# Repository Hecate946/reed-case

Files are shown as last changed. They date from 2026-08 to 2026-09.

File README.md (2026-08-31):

# Reed case CAD

OpenSCAD source for the current H946 reed-case prototype.

## Closure hardware

The custom pushbutton / leaf-spring / hook / striker system has been removed.
The case now mounts one purchased **Alise CA100S-4P (CA100-4P) 40 mm double-roller catch** centered in the front service strip. The roller body sits on an integrated base pedestal just below the case seam; the matching striker screws to a recessed ledge on the lid. There is no external button. Pulling the lid apart releases the rollers.

Useful OpenSCAD views:

```scad
view = "roller_catch_mechanism";
view = "roller_catch_hardware";
view = "case_open";
view = "case_closed";
```

The purchased catch is not exported as a printable part. `make export-case` exports the base and lid with the mounting bosses, locating seats, and screw pilots already integrated.

### Flush Alise catch integration
The centered front catch housing now uses the seller drawing directly: the 40 x 9 mm, 10 mm-high main catch sits in a top-loading recess molded into a locally 12.8 mm-thick front wall. The exterior remains seamless. The 22 x 8 mm striker plate is recessed flush into the lid rim, with only its 5 mm tongue projecting into the rollers. The ordinary shell remains 4.2 mm thick away from the catch.

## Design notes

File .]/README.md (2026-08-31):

# Reed case CAD

OpenSCAD source for the **premium-style clarinet reed case prototype**.
The project is intentionally small: one tray design, one enclosure design, one
configuration file, and one source-zip script.

## Prototype concept

- compact **190 x 99 x 31.5 mm** enclosure sized around one full-width 10x2 reed cartridge
- integrated shallow **humidity bay** below the cartridge, holding **2 x Boveda Size 8** packs under a simple vented drop-in cover
- one removable double-sided 10-reed-per-face tray / cartridge
- four D4x2 retention points per tray
- replaceable **2 mm metal hinge pin** with alternating printed knuckles
- two full-height, sharp-cornered mirrored stepped spring-support blocks
- separate moving latch plate with a large **48 x 6.65 mm** exterior push button
- one closing tongue with a `---\` outward face and a flat-underside catch
- no guide rails and no stop tabs; the inner front wall is the locked stop
- shallow slide pan recessed into the base floor, outer bottom shell intact
- no modeled spring; the future leaf spring remains a separate metal part
- recessed lid latch groove with no protruding lid striker
- continuous **2 x 175 mm silicone O-ring** prototype seal
- shallow `ASASI` mark at the lid's bottom right, controlled from `src/config.scad`
- dark-teal shell / white-tray colors in OpenSCAD previews only

The cartridge sits on a raised support frame above the humidity bay, leaving a
vented service cavity below for the two Boveda packs. The side-latch hardware stays
in its own narrow service strips beside the cartridge.

### Leaf-spring mounting architecture

Only the case-side stepped solids exist in CAD. They intentionally have no
screw holes, spring channels, rounded corners, or enclosed cutouts. From the
top, each has a full-width back section and a half-width outward front leg;
the right piece is the exact horizontal mirror of the left. Open
`bottom_case` to debug the bottom piece alone; the real fused mount solids are
orange. Use `leaf_spring_mount_pair` to inspect both blocks without the
case. `left_leaf_spring_mount` and `right_leaf_spring_mount` expose each module
separately for dimension changes and standalone STL checks.
Each piece fits within a **13.0 x 8.5 x 8.45 mm** envelope and extends from the
base floor to the case seam. The front step depth and outer-foot width are
separate parameters in `src/config.scad`. The mount centers sit at **-42 and
+42 mm**, so the real leaf spring spans about 84 mm between the outer feet.
That span is deliberate: it clears the much wider latch plate. Expect to need
**0.5 mm or thicker** spring steel, because a thin 0.3 mm leaf over this span
delivers well under 1 N at full travel and feels dead.

### Moving latch piece

The latch is a separate component rather than part of the printable base. It is
a single flat plate, **56.0 x 4.0 mm** in plan, sliding in a **1.00 mm** deep pan
recessed into the interior base floor. The pan leaves **2.80 mm** of floor skin
and never breaks the exterior bottom shell. The pan's side walls guide the plate
in X; its rear wall sits 0.30 mm behind the fully pressed position and acts only
as an overtravel backstop.

There are no guide rails and no stop tabs anywhere in the design. At rest the
leaf spring pushes the plate outward until its full-width front face lands flat
on the inner front wall, so the locked stop is 56 mm of wall instead of two
small tabs.

Dropping the plate into the pan is what lets the button grow. The interior floor
sits above the exterior mid-plane, so a vertically centered button on the base
face is height-limited by the floor; the pan removes that limit. The integral
button is now **48.0 x 6.65 mm** with a **2.60 mm** corner radius, covering about
**13.7%** of the front face. Its center is derived from `x = 0` and
`z = v2_base_h / 2`, so it stays exactly centered. Its **2.60 mm** travel leaves
it exactly flush with the case wall when fully pressed.

#### Closing tongue and catch

One solid rises above the seam. Read its outward face top-down and it is
literally `---\`: a flat crown, then a single straight ramp falling outward to a
protruding catch. The descending lid wall rides that ramp and drives the whole
latch inward; when the lid pocket lines up, the spring snaps the catch in. Every
convex edge carries one **0.55 mm** radius and the single concave corner carries
a **0.35 mm** fillet.

The catch underside is **horizontal**. This is the important change from the old
hook. The seal load presses straight up into a flat **1.0 mm** deep bearing land
and cannot back-drive the latch. Previously the only thing holding the lid was a
sloped hook top at roughly 35 degrees, which meant the O-ring's own force was
continuously trying to eject the latch and the leaf spring was fighting the seal
the entire time the case was closed. Nothing carries the lock now except that
flat land.

Sequence: press the lid down to the seam, the catch slips in with **0.20 mm** of
room above and below, release, and the seal lifts the lid **0.20 mm** until the
pocket floor lands on the land. Locked O-ring squeeze is **0.35 mm**, about
17.5% of the 2 mm cord. Pressing the button retracts the catch **1.55 mm** past
the wall face, with 1.05 mm of travel to spare.

The tongue is set back **0.50 mm** from the plate's front face. Without that
setback the fillet under the catch, not the flat land, would be the first thing
the lid pocket touches, and the seat height would be wrong. `make check` catches
that case directly.

#### Lid pocket

The lid owns only a plain rounded pocket, **22.6 mm** wide and **1.80 mm** deep,
leaving **1.60 mm** of solid outer wall skin. Its floor sits **2.80 mm** above the
seam. The previous version placed it 1.60 mm above the seam, which left only
**0.15 mm** of lid material between the O-ring gland roof and the pocket floor.
That web is unprintable; it is now **1.35 mm** and is asserted.

The pocket roof is derived, not hand-set: it clears the point where the closing
ramp crosses the lid wall face, plus 0.25 mm. Change the tongue height or the
catch extension and the pocket follows.

All functional values are grouped under `MOVING FRONT LATCH PIECE` and
`CLOSING TONGUE AND CATCH` in `src/config.scad`.

#### Known limitation

The button opening is a straight 48 x 6.65 mm hole through the front wall into
the sealed interior. The O-ring seals the lid seam properly and then the case
breathes through the latch. This redesign does not fix that and it is probably
not fixable with an external push button; it needs either a gasketed button boot
or a latch that acts through the seam instead of through the wall. Decide that
before treating the Boveda humidity behaviour as real.

#### Views

Use `bottom_case` for the installed assembly, `bottom_case_shell` for the base
and its openings alone, `bottom_case_latch_fit` for a transparent fit view, and
`bottom_case_latch_pressed` for maximum inward travel.
`latch_groove_lock_detail` shows the catch seated on its land at the resting lid
height, `latch_groove_closing_entry` shows the moment of entry with the lid
pressed to the seam, `latch_button_release_detail` shows the catch fully
retracted, and `top_lid_latch_groove` isolates the pocketed center-front lid
section. Use `latch_piece` for the standalone moving component.

Use `humidity_cassette` or `humidity_bay_open` to inspect the humidity bay with its cover lifted.
Use `humidity_bay_closed` to preview the lid seated on its ledge.
`case_exploded` now shows the base, the vented humidity cover over two packs, the full reed
cartridge above it, and the lid.

## Files that matter

```text
src/config.scad          dimensions + hardware + easy customization
src/main.scad            interactive OpenSCAD preview
src/assembly.scad        views and part routing
src/parts/tray.scad      reed tray geometry
src/parts/case.scad      enclosure geometry
src/parts/spring_mounts.scad
src/parts/calibration.scad
src/lib/                 small reusable geometry/hardware helpers
Makefile                 all checks / exports
scripts/make-source-zip.sh
```

## Normal workflow

Open `src/main.scad` in OpenSCAD. The file intentionally keeps every useful
`view = ...` option commented directly below the active fine-mesh view, so
switching views stays one-line simple:

```text
bottom_case
humidity_cassette
bottom_case_boveda_size_60
bottom_case_shell
bottom_case_latch_fit
bottom_case_latch_pressed
latch_piece
latch_groove_lock_detail
latch_groove_closing_entry
latch_button_release_detail
top_lid_latch_groove
leaf_spring_mount_pair
left_leaf_spring_mount
right_leaf_spring_mount
case_open
case_closed
case_exploded
case_closed_front
bottom_case_with_trays
lid_seal
tray
print_layout
```

All functional dimensions are in `src/config.scad`.

### Reed reference model

Preview reeds use the footprint and thickness envelope of a French/Boehm Bb
clarinet reed: **67.5 mm long, 13.15 mm maximum width, 11.0 mm heel width,
34.1 mm vamp, 3.05 mm nominal heel thickness, and 0.10 mm tip thickness**.
The intended reference is the Vandoren Traditional Bb strength 3.5 (CR1035).
Vandoren identifies that product/strength but does not publish its proprietary
full manufacturing profile, so the preview uses documented clarinet-reed
measurements for fit and clearance rather than claiming an exact factory cut.

### Easy tray exports

From the project root, use whichever one you need:

```bash
make export-tray-full         # complete assembled tray -> one STL
make export-humidity-cover    # vented humidity cover
make export-tray-face-a       # only face A
make export-tray-face-b       # only face B
make export-tray              # both support-free shell halves
```

By default these use the fast prototype mesh. For the final/high-quality mesh, add `PROFILE=fine`:

```bash
make export-tray-full PROFILE=fine
```

The single-part outputs are written to:

```text
build/reed-case-prototype/tray/tray_complete.stl
build/reed-case-prototype/tray/tray_face_a.stl
build/reed-case-prototype/tray/tray_face_b.stl
```

Run `make help` at any time to see every available command.

### Export the prototype

```bash
make check
make export
```

The printable files are written to:

```text
build/reed-case-prototype/case_base.stl
build/reed-case-prototype/case_lid.stl
build/reed-case-prototype/latch/latch_piece.stl
build/reed-case-prototype/spring-mounts/left_leaf_spring_mount.stl
build/reed-case-prototype/spring-mounts/right_leaf_spring_mount.stl
build/reed-case-prototype/tray-parts/tray_face_a.stl
build/reed-case-prototype/tray-parts/tray_face_b.stl
build/reed-case-prototype/fit_coupon.stl
```

The current cartridge has **no middle/core layer**. It is built from two
slightly thicker mirrored shell halves that join directly back-to-back.
`make export-tray` exports those two support-free halves; `make export-tray-full`
exports the fused cartridge as one STL. The heel-side 65% uses five smooth
longitudinal breathing runners per reed lane, while the tip-side 35% is fully
open air.

### Quick visual render

```bash
make render
```

This writes the open, closed, front, exploded, tray-fit, and seal views to `build/renders/`.

### Share the latest source

```bash
make zip
```

This always replaces one file at the project root:

```text
reed-case-source.zip
```

Upload that ZIP when you want another design/code pass. There are no dated or
numbered source archives created by the project.

## First physical test

Use inexpensive PLA/PETG. Before committing to a long print, print
`fit_coupon.stl` and verify the actual 2 mm hinge rod and D4x2 hardware fit.
For the complete prototype, install the real hinge pin, magnets/steel targets,
silicone cord used for reed retention, and the intended O-ring. Test the chosen
spring-retention method before installing the real metal spring. Evaluate the case
size, reed access, tray removal, magnet feel, latch force, hinge feel, and seal
compression before changing anything for CNC aluminum.

## Side latch metal hardware

The current case uses two slim side buttons with bowed 301 stainless leaf
springs hidden behind removable stainless cover plates. See
`hardware/SIDE_LATCH_HARDWARE.md`. Export the cutting templates with:

```bash
make export-side-latch-hardware
```

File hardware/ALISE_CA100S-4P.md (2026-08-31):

# Alise CA100S-4P roller catch

Purchased part: Alise 40 mm silver double-roller catch, Amazon ASIN B0D8L6GJWK.
Model: **CA100S-4P**. Manufacturer part: **CA100-4P**.

Seller-published dimensions used by the CAD:

- Main mounting plate: **40 x 9 mm**
- Main mounting-hole pitch: **30 mm**
- Main roller/body span: **24 mm**
- Overall catch height: **10 mm**
- Published mounting-hole diameter: **4 mm**
- Striker mounting plate: **22 x 8 mm**
- Striker mounting-hole pitch: **15 mm**
- Striker tongue rise: **5 mm**

The listing also describes the nominal product envelope as 40 x 25 x 10 mm.
The detailed seller dimension image is used for the mounting plate geometry.
Plate thickness and small radii are not published; the OpenSCAD hardware model
uses preview-only approximations for those non-fit-critical details. Measure the
delivered parts before freezing a production revision.

The printed case has 2.5 mm pilot holes under both pieces. Adjust
`roller_catch_mount_pilot_d` and `roller_catch_strike_pilot_d` in `src/config.scad`
to match the screws you actually use.

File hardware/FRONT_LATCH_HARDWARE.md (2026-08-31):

# Center front-latch hardware

The case uses one centered front push button with the same latch kinematics as
the previous side mechanism: the lid cams the rounded catch inward, the leaf
spring returns the latch outward into the lid groove, and pressing the button
retracts the catch. At full press the button face is flush with the front wall.

## Leaf spring

Prototype material: **301 full-hard stainless spring/shim stock, 0.006 in
(0.1524 mm)**.

Use `front_leaf_spring_strip.dxf` as the cutting/drilling template:

- about 35 mm long x 7 mm high
- two 2.3 mm clearance holes on a 31 mm screw span
- one spring is required

Install it with a shallow outward pre-bow. The exact force should be tuned on a
physical prototype; 0.006 in is the intended starting thickness.

## Interior cover

Use `front_latch_cover_plate.dxf`. Make **one** from:

- 0.030 in / 0.76 mm 304 stainless steel
- deburred edges recommended

The plate screws into the two printed support blocks and hides the spring and
moving latch from the cartridge area. The same two screws clamp the spring ends.

Prototype fasteners:

- 2x M2 x 5 mm thread-forming screws
- 1.6 mm printed pilot holes
- 2.3 mm cover/spring clearance holes

## Export

```bash
make export-front-latch-hardware
```

Outputs are written under:

`build/reed-case-prototype/front-latch-hardware/`

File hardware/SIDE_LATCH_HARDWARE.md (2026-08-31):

# Dual side-latch hardware

The side buttons use the same latch motion as the previous front button: the
lid cams each latch inward, the spring pushes the catch outward into the lid
groove, and pressing the button retracts the catch. There are two mirrored,
independent side mechanisms.

## Leaf spring

Target material: **301 full-hard stainless spring/shim stock, 0.006 in
(0.1524 mm)**.

Flat blank from `side_leaf_spring_strip.dxf`:
- 40 mm x 7 mm nominal blank
- two 2.3 mm screw holes on the 36 mm screw span
- make two identical pieces

At assembly, put a shallow outward bow in the strip so the center rises about
2.6-2.7 mm from the screw/cover plane. The two cover screws clamp the ends.
The button pushes the latch inward and nearly flattens this bow; the strip
returns the latch outward when released.

The design target is intentionally tunable. Start at 0.006 in. If the buttons
feel too light after the first physical prototype, try 0.007 or 0.008 in.
Do not jump to thick ordinary sheet metal; spring force rises roughly with the
cube of thickness.

For reference, using E ~= 193 GPa, a 36 mm span, 7 mm strip height, 0.1524 mm
thickness, and 2.6 mm center motion gives a simple beam estimate of roughly
1.1-4.3 N depending on how rigidly the ends behave. The fixed-end estimate is
about 708 MPa peak bending stress, below the ~965 MPa minimum 0.2% yield value
commonly specified for full-hard 301. This is only a prototype sizing model;
final feel and fatigue life should be validated physically.

## Metal mechanism cover

Use `side_latch_cover_plate.dxf`. Make **two identical pieces** from:
- 0.030 in / 0.76 mm 304 stainless steel
- deburred edges recommended

The plate screws into the two printed spring-support blocks and completely
shields the spring from the reed cartridge/user. The same two screws also
clamp the spring ends behind the plate.

Recommended prototype screws:
- 2x M2 x 5 mm thread-forming screws per side
- printed supports have 1.6 mm pilot holes
- cover/spring blanks have 2.3 mm clearance holes

For a more production-like version later, replace the thread-forming screw
joint with a suitable miniature threaded insert or molded metal boss after the
case material/process is finalized.

## Export commands

```bash
make export-side-latch-hardware
```

This produces STL reference models plus both DXF cutting templates under:

`build/reed-case-prototype/side-latch-hardware/`

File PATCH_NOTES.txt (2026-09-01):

V6 compact-depth update
- Keeps full 133.35 mm Size 60 long dimension.
- Uses a 79.80 mm installed short-axis footprint by folding/tucking the flexible pouch corners.
- Shortens active 8-reed tray depth from 93.00 mm to 82.40 mm.
- Shortens outer case depth from 101.90 mm to 91.30 mm.
- Case width remains 177.648 mm and closed height remains 22.10 mm.
- Humidity bay short dimension is 80.10 mm including 0.15 mm clearance each side.
- Honeycomb reduced from 9 to 8 rows to preserve edge/web strength.
- Size 60 preview now represents the installed folded short-axis envelope.
- O-ring updated to 157 mm ID; calculated installation stretch ~2.04%.
- Full `make check` passes.

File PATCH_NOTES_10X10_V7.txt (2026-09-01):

10x10 reed tray update (v7)

- Active double-sided tray increased from 8 reeds per face to 10 reeds per face (20 total).
- Existing compact short-depth geometry, Size 60 bay, left digital hygrometer, centered latch, hinge, O-ring seal, and tray thickness are unchanged.
- Case width expands only as required by the two additional reed lanes per face.
- Archived/frozen designs are untouched.

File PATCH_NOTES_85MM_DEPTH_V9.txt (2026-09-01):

V9 85 mm depth compacting patch

Changes:
- Reduces active 10x10 reed tray depth from 82.40 mm to 76.10 mm.
- Keeps full 67.50 mm reed length with ~1.20 mm longitudinal clearance at each end when centered.
- Reduces folded Size 60 short-axis design footprint from 79.80 mm to 73.80 mm.
- Reduces humidity-cover honeycomb rows from 8 to 7 to preserve a solid bridge at the semicircle finger notch.
- Changes the O-ring target from 177 mm ID to 173 mm ID to maintain proper stretch on the shorter case perimeter.
- Resulting main case body depth is 85.00 mm while width and height remain 209.25 mm and 22.10 mm.
- No changes to latch plan position, hinge architecture, seam lowering, hygrometer, tray width/capacity, or total closed height.

Validation:
- `make check` passes all OpenSCAD views/parts.

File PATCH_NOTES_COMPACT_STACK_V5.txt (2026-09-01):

Compact Size-60 stack v5

Changes:
- Added a true centered semicircular finger notch to the front edge of the Size-60 humidity-cover lid.
- Reduced active 8-reed tray guide height from 4.20 mm to 3.70 mm.
- Reduced active 8-reed tray face thickness from 1.65 mm to 1.30 mm.
- Reduced Size-60 modeled compressed thickness from 5.40 mm to 5.10 mm.
- Reduced humidity-cover thickness from 1.40 mm to 1.20 mm.
- Reduced tray/cover vertical gap from 0.15 mm to 0.10 mm.
- Reduced base floor from 2.80 mm to 2.50 mm and lid roof from 2.80 mm to 2.20 mm.
- Reduced Size-60 planar clearance from 0.25 mm to 0.15 mm per side.
- Reduced total closed case height to 22.10 mm while retaining clearance, latch, hinge, hygrometer, and continuous O-ring geometry.

Validation:
- Full OpenSCAD make check passed with no ERROR output.
- CGAL STL exports passed for case_base, case_lid, humidity_cover, and tray.

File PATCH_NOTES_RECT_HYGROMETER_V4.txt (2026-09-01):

Compact Size-60 + rectangular digital hygrometer v4

- Replaces the 50 x 15 mm round analog gauge with the exact device envelope
  shown by the user: 1.87 x 1.12 x 0.57 in = 47.50 x 28.45 x 14.48 mm.
- Rotates the device in plan so only its 28.45 mm side consumes case width.
- Flips the active layout so the hygrometer occupies the left-side bay and the
  8-reed-per-face / Boveda Size 60 stack occupies the opposite side.
- Keeps the centralized Alise latch, Size 60 bay, reed tray structure, hinge,
  and continuous perimeter O-ring architecture.
- Narrows the outer case from about 199.6 mm to about 177.65 mm while keeping
  case depth about 101.9 mm.
- Lowers total closed height slightly to 25.20 mm.
- Uses a 164 x 2 mm O-ring model to keep stretch in the intended range.
- Full `make check` and CGAL case base/lid export passed.

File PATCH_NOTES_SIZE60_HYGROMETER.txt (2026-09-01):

NEW ACTIVE DESIGN: compact Size 60 + side hygrometer

Frozen previous design:
  frozen/compact_size8_20260831/

Active changes:
- 8 reeds per face (16 total), same double-sided H946 tray construction
- one snug Boveda Size 60 bay directly below the reed tray
- 50 x 15 mm hygrometer envelope in a 1.4 mm thin annular cradle on the left
- same centered Alise CA100S-4P latch architecture and rounded case language
- total height targeted at 25.0 mm
- base magnets disabled in this compact variant; tray is located by a close XY well and closed lid
- continuous perimeter O-ring retained

Prototype hygrometer fit must be tuned after measuring the delivered gauge with calipers.

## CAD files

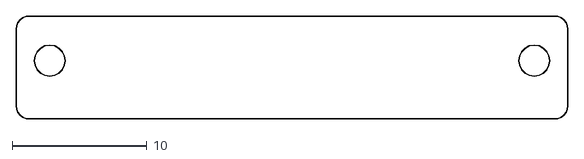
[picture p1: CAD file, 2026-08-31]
.]/hardware/side_latch_cover_plate.dxf
41.0 x 7.65

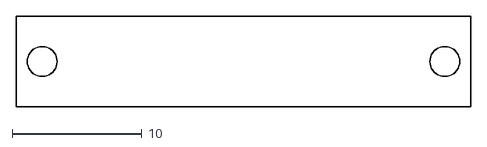
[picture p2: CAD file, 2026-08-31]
hardware/front_leaf_spring_strip.dxf
35.0 x 7.00

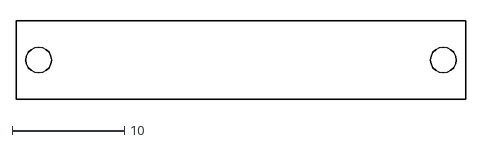
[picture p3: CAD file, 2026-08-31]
.]/hardware/side_leaf_spring_strip.dxf
40.0 x 7.00

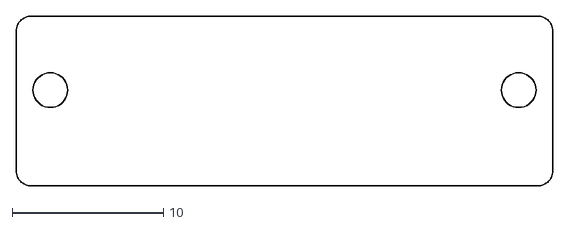
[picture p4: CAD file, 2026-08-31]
hardware/front_latch_cover_plate.dxf
35.5 x 11.2

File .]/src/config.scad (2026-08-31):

/*
  Reed case configuration.

  Edit this file for dimensions and hardware. The model has one supported
  product architecture: the single 10-reed-per-face cartridge prototype.
  `mesh_profile` only changes
  tessellation/detail; it never changes functional dimensions.
*/

mesh_profile_default = "prototype";
active_mesh_profile = is_undef(mesh_profile) ? mesh_profile_default : mesh_profile;
assert(active_mesh_profile == "prototype" || active_mesh_profile == "fine",
       str("Unknown mesh_profile: ", active_mesh_profile));

is_fast_mesh = active_mesh_profile == "prototype";
$fn = is_fast_mesh ? 24 : ($preview ? 56 : 96);
epsilon = 0.02;

// ---------------------------------------------------------------------------
// REED TRAY
// ---------------------------------------------------------------------------

// The retained Behn reference stays at its original five reeds per face.
reeds_per_face = 5;

// New H946 open-air cartridge capacity.
tray_reeds_per_face = 10;

// Boveda Size 8 design envelope. Measure the exact packs you plan to use
// before freezing production dimensions.
boveda_w = 69.85;
boveda_d = 63.50;
boveda_h = 4.50;
boveda_clearance = 1.00;
boveda_slide_clearance = 1.00;
boveda_thickness_clearance = 0.60;

// Boveda Size 60 scale-reference envelope. Boveda publishes the planar size
// as 3.5 x 5.25 in (88.90 x 133.35 mm). Filled thickness varies with moisture
// content, so 6 mm is an intentionally editable preview estimate only.
boveda_size_60_w = 133.35;
boveda_size_60_d = 88.90;
boveda_size_60_h_preview = 6.00;
boveda_size_60_corner_r_preview = 4.00;

// Vandoren Traditional Bb clarinet reed, strength 3.5 (CR1035), modeled
// from published/measured clarinet-reed geometry. Vandoren identifies CR1035
// as its Traditional Bb 3.5 reed but does not publish a full manufacturing
// drawing, so the dimensions below use the best documented physical envelope:
// 67.5 mm total length, 13.15 mm maximum/tip width, 34.1 mm vamp length,
// 2.8-3.25 mm heel thickness and 0.09-0.11 mm tip thickness.
// The 11.0 mm heel width follows standard French/Boehm reed finishing practice.
reed_length = 67.50;
reed_max_w = 13.15;
reed_heel_w = 11.00;
reed_vamp_length = 34.10;
reed_max_h = 3.05;
reed_tip_h = 0.10;
reed_tip_round_depth = 1.25;
reed_tip_clearance = 0.50;
reed_end_margin = 7.50;

// Reed passages and tray body.
reed_slot_clear_w = 14.30;
tray_guide_t = 1.10;
tray_guide_h = 4.20;
tray_face_t = 1.20;
tray_corner_r = 3.00;
tray_border_w_min = 6.40;
tray_d = 87.50;

tray_passage_field_w = reeds_per_face * reed_slot_clear_w +
                       (reeds_per_face - 1) * tray_guide_t;
tray_core_side_wall_min = 1.50;
tray_body_w = max(tray_passage_field_w + 2 * tray_border_w_min,
                  boveda_w + 2 * boveda_clearance +
                  2 * tray_core_side_wall_min);
tray_border_w = (tray_body_w - tray_passage_field_w) / 2;
tray_body_corner_r = min(tray_corner_r,
                         max(tray_border_w - 0.50, 0.50));
tray_w = tray_body_w; // full sweep width for band-groove cutters

tray_core_h = boveda_h + boveda_thickness_clearance;
tray_total_h = tray_core_h + 2 * (tray_face_t + tray_guide_h);

// Ventilation field.
tray_air_hole_d = 1.60;
tray_air_rows = 22;
tray_air_columns = 3;
tray_air_column_pitch = 4.30;
tray_air_edge_relief = 0.18;
tray_air_edge_relief_h = 0.30;
tray_air_edge_steps = 2;
tray_platform_top_chamfer = 0.20;
tray_wall_top_chamfer = 0.20;
tray_feature_fuse_overlap = 0.10;
tray_reed_plane_edge_margin = 1.25;
tray_pack_vent_clearance = 0.25;

// Reed support rails.
rail_h = 0.55;
rail_w = 2.00;
rail_rows = 11;
stock_rails_enable = true;

// Reference-tray details.
lane_numbers_enable = true;
lane_number_size = 2.60;
lane_number_depth = 0.50;
lane_number_margin = 0.80;
lane_number_font = "Liberation Sans:style=Bold";
front_plane_cutout_enable = false;
guide_walls_full_length = true;
aperture_heel_margin = 2.00;
aperture_tip_margin = 1.20;
guide_end_taper = tray_guide_h;

// Round silicone cord used to retain reeds.
elastic_band_d = 2.00;
elastic_band_clearance = 0.25;
elastic_band_seat_depth = 0.35;
elastic_band_row_gaps = [8.5, 11.5];

// Humidity-pack channel.
tray_pack_slot_depth = boveda_d + boveda_slide_clearance;
tray_pack_stop_y = tray_d / 2 - tray_pack_slot_depth;
tray_pack_seated_y = tray_d / 2 - boveda_slide_clearance - boveda_d / 2;
tray_pack_support_w = 1.60;
tray_core_heel_bridge_d = 2.00;

// Tray retention hardware. Four identical pockets exist on each tray face so
// a tray can be flipped. Prototype recommendation: magnets in the case base,
// mild-steel discs in both tray faces.
tray_magnet_d = 4.00;
tray_magnet_h = 2.00;
magnet_d_clearance = 0.20;
magnet_h_clearance = 0.15;
magnet_entry_chamfer = 0.15;
magnet_lane_clearance = 0.25;
magnet_wall_min = 1.00;
tray_magnet_edge_inset = 12.00;
tray_magnet_y = tray_d / 2 - tray_magnet_edge_inset;
tray_magnet_x = (tray_body_w - tray_border_w) / 2;

// ---------------------------------------------------------------------------
// CASE
// ---------------------------------------------------------------------------

// Compact enclosure for one full-width H946 10-reed-per-face cartridge.
// An integrated humidity bay now lives under the cartridge, so the case is
// slightly taller than the earlier no-Boveda variant. Width/depth and the
// latch/hinge logic stay intentionally stable.
v2_case_w = 190.00;
v2_case_d = 99.00;
v2_case_h = 31.50;
v2_base_h = 16.25;
v2_lid_h = v2_case_h - v2_base_h;
v2_corner_r = 9.00;
v2_wall = 3.40;
v2_base_floor_t = 3.80;
v2_lid_roof_t = 3.00;

// One centered cartridge-registration well. Magnets retain the cartridge;
// the shallow well only locates it in X/Y and prevents lateral sliding.
v2_tray_xy_clearance = 0.35;
v2_tray_recess_depth = 0.60;
v2_tray_recess_w = tray_body_w_open() + 2 * v2_tray_xy_clearance;
v2_tray_recess_d = tray_d_open() + 2 * v2_tray_xy_clearance;
v2_tray_recess_r = tray_body_corner_r_open() + v2_tray_xy_clearance;
v2_tray_x = 0;
// Keep the cartridge slightly hinge-ward to preserve the front latch/service
// strip. With the shorter new cartridge this also leaves comfortable clearance
// behind the tip-protection edge.
v2_tray_y = -4.50;
v2_inner_w = v2_case_w - 2 * v2_wall;
v2_inner_d = v2_case_d - 2 * v2_wall;
v2_side_margin = (v2_inner_w - v2_tray_recess_w) / 2;
v2_front_margin = v2_inner_d / 2 -
                  (v2_tray_y + v2_tray_recess_d / 2);
v2_back_margin = v2_inner_d / 2 +
                 v2_tray_y - v2_tray_recess_d / 2;

// Four D4x2 magnets under the single cartridge. The base floor is deliberately
// thick enough to leave >1 mm of material below these pockets.
v2_floor_magnet_depth = tray_magnet_h + magnet_h_clearance;


// ---------------------------------------------------------------------------
// INTEGRATED HUMIDITY BAY + VENTED DROP-IN LID (2 x Boveda Size 8)
// ---------------------------------------------------------------------------
// Instead of a full removable cassette, the case now uses a shallow humidity
// bay built directly into the base floor. Two Size 8 packs sit in divided
// wells and a thin removable perforated lid simply rests on a surrounding
// ledge above them.
v2_humidity_bay_corner_r = 3.00;
v2_humidity_bay_pack_clearance = 0.80;
v2_humidity_bay_divider_t = 2.40;
v2_humidity_bay_pocket_w =
    boveda_w + 2 * v2_humidity_bay_pack_clearance;
v2_humidity_bay_pocket_d =
    boveda_d + 2 * v2_humidity_bay_pack_clearance;
v2_humidity_bay_inner_w =
    2 * v2_humidity_bay_pocket_w + v2_humidity_bay_divider_t;
v2_humidity_bay_inner_d = v2_humidity_bay_pocket_d;
v2_humidity_bay_opening_w = v2_humidity_bay_inner_w + 5.10;
v2_humidity_bay_opening_d = v2_humidity_bay_inner_d + 5.10;
v2_humidity_bay_x = 0;
v2_humidity_bay_y = v2_tray_y;
v2_humidity_bay_floor_z = v2_base_floor_t;
v2_humidity_bay_depth = 6.60;
v2_humidity_bay_top_z = v2_humidity_bay_floor_z + v2_humidity_bay_depth;

// Tray-support frame around the bay. The reed cartridge lands on this frame,
// leaving the center open for the humidity bay cover.
v2_tray_bottom_z = v2_humidity_bay_top_z + 0.20;
v2_tray_support_h = v2_tray_bottom_z - v2_base_floor_t;
v2_tray_support_outer_w = v2_tray_recess_w;
v2_tray_support_outer_d = v2_tray_recess_d;
v2_tray_support_outer_r = v2_tray_recess_r;
v2_tray_support_inner_w = v2_humidity_bay_opening_w;
v2_tray_support_inner_d = v2_humidity_bay_opening_d;
v2_tray_support_inner_r = v2_humidity_bay_corner_r;

// Removable vented cover.
v2_humidity_cover_t = 1.80;
v2_humidity_cover_clearance = 0.22;
v2_humidity_cover_seat_w = 1.30;
v2_humidity_cover_seat_depth = 0.95;
v2_humidity_cover_w = v2_tray_support_inner_w - 2 * v2_humidity_cover_clearance;
v2_humidity_cover_d = v2_tray_support_inner_d - 2 * v2_humidity_cover_clearance;
v2_humidity_cover_corner_r = max(v2_tray_support_inner_r - v2_humidity_cover_clearance, 0.8);
v2_humidity_cover_z = v2_tray_bottom_z - v2_humidity_cover_t;
v2_humidity_cover_finger_r = 7.00;
v2_humidity_cover_finger_inset = 0.10;
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

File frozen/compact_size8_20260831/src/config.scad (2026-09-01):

/*
  Reed case configuration.

  Edit this file for dimensions and hardware. The model has one supported
  product architecture: the single 10-reed-per-face cartridge prototype.
  `mesh_profile` only changes
  tessellation/detail; it never changes functional dimensions.
*/

mesh_profile_default = "prototype";
active_mesh_profile = is_undef(mesh_profile) ? mesh_profile_default : mesh_profile;
assert(active_mesh_profile == "prototype" || active_mesh_profile == "fine",
       str("Unknown mesh_profile: ", active_mesh_profile));

is_fast_mesh = active_mesh_profile == "prototype";
$fn = is_fast_mesh ? 24 : ($preview ? 56 : 96);
epsilon = 0.02;

// ---------------------------------------------------------------------------
// REED TRAY
// ---------------------------------------------------------------------------

// The retained Behn reference stays at its original five reeds per face.
reeds_per_face = 5;

// New H946 open-air cartridge capacity.
tray_reeds_per_face = 10;

// Boveda Size 8 design envelope. Measure the exact packs you plan to use
// before freezing production dimensions.
boveda_w = 69.85;
boveda_d = 63.50;
boveda_h = 4.50;
boveda_clearance = 1.00;
boveda_slide_clearance = 1.00;
boveda_thickness_clearance = 0.60;

// Boveda Size 60 scale-reference envelope. Boveda publishes the planar size
// as 3.5 x 5.25 in (88.90 x 133.35 mm). Filled thickness varies with moisture
// content, so 6 mm is an intentionally editable preview estimate only.
boveda_size_60_w = 133.35;
boveda_size_60_d = 88.90;
boveda_size_60_h_preview = 6.00;
boveda_size_60_corner_r_preview = 4.00;

// Vandoren Traditional Bb clarinet reed, strength 3.5 (CR1035), modeled
// from published/measured clarinet-reed geometry. Vandoren identifies CR1035
// as its Traditional Bb 3.5 reed but does not publish a full manufacturing
// drawing, so the dimensions below use the best documented physical envelope:
// 67.5 mm total length, 13.15 mm maximum/tip width, 34.1 mm vamp length,
// 2.8-3.25 mm heel thickness and 0.09-0.11 mm tip thickness.
// The 11.0 mm heel width follows standard French/Boehm reed finishing practice.
reed_length = 67.50;
reed_max_w = 13.15;
reed_heel_w = 11.00;
reed_vamp_length = 34.10;
reed_max_h = 3.05;
reed_tip_h = 0.10;
reed_tip_round_depth = 1.25;
reed_tip_clearance = 0.50;
reed_end_margin = 7.50;

// Reed passages and tray body.
reed_slot_clear_w = 14.30;
tray_guide_t = 1.10;
tray_guide_h = 4.20;
tray_face_t = 1.20;
tray_corner_r = 3.00;
tray_border_w_min = 6.40;
tray_d = 87.50;

tray_passage_field_w = reeds_per_face * reed_slot_clear_w +
                       (reeds_per_face - 1) * tray_guide_t;
tray_core_side_wall_min = 1.50;
tray_body_w = max(tray_passage_field_w + 2 * tray_border_w_min,
                  boveda_w + 2 * boveda_clearance +
                  2 * tray_core_side_wall_min);
tray_border_w = (tray_body_w - tray_passage_field_w) / 2;
tray_body_corner_r = min(tray_corner_r,
                         max(tray_border_w - 0.50, 0.50));
tray_w = tray_body_w; // full sweep width for band-groove cutters

tray_core_h = boveda_h + boveda_thickness_clearance;
tray_total_h = tray_core_h + 2 * (tray_face_t + tray_guide_h);

// Ventilation field.
tray_air_hole_d = 1.60;
tray_air_rows = 22;
tray_air_columns = 3;
tray_air_column_pitch = 4.30;
tray_air_edge_relief = 0.18;
tray_air_edge_relief_h = 0.30;
tray_air_edge_steps = 2;
tray_platform_top_chamfer = 0.20;
tray_wall_top_chamfer = 0.20;
tray_feature_fuse_overlap = 0.10;
tray_reed_plane_edge_margin = 1.25;
tray_pack_vent_clearance = 0.25;

// Reed support rails.
rail_h = 0.55;
rail_w = 2.00;
rail_rows = 11;
stock_rails_enable = true;

// Reference-tray details.
lane_numbers_enable = true;
lane_number_size = 2.60;
lane_number_depth = 0.50;
lane_number_margin = 0.80;
lane_number_font = "Liberation Sans:style=Bold";
front_plane_cutout_enable = false;
guide_walls_full_length = true;
aperture_heel_margin = 2.00;
aperture_tip_margin = 1.20;
guide_end_taper = tray_guide_h;

// Round silicone cord used to retain reeds.
elastic_band_d = 2.00;
elastic_band_clearance = 0.25;
elastic_band_seat_depth = 0.35;
elastic_band_row_gaps = [8.5, 11.5];

// Humidity-pack channel.
tray_pack_slot_depth = boveda_d + boveda_slide_clearance;
tray_pack_stop_y = tray_d / 2 - tray_pack_slot_depth;
tray_pack_seated_y = tray_d / 2 - boveda_slide_clearance - boveda_d / 2;
tray_pack_support_w = 1.60;
tray_core_heel_bridge_d = 2.00;

// Tray retention hardware. Four identical pockets exist on each tray face so
// a tray can be flipped. Prototype recommendation: magnets in the case base,
// mild-steel discs in both tray faces.
tray_magnet_d = 4.00;
tray_magnet_h = 2.00;
magnet_d_clearance = 0.20;
magnet_h_clearance = 0.15;
magnet_entry_chamfer = 0.15;
magnet_lane_clearance = 0.25;
magnet_wall_min = 1.00;
tray_magnet_edge_inset = 12.00;
tray_magnet_y = tray_d / 2 - tray_magnet_edge_inset;
tray_magnet_x = (tray_body_w - tray_border_w) / 2;

// ---------------------------------------------------------------------------
// CASE
// ---------------------------------------------------------------------------

// Ultra-compact enclosure for one full-width H946 10-reed-per-face cartridge.
// The main shell is derived directly from the cartridge registration envelope:
// there is no decorative/service margin around the tray. The only extra
// footprint is the centered local latch housing at the front and the hinge at
// the rear. This is the Option-C architecture.
v2_tray_xy_clearance = 0.35;
v2_wall = 4.60;
v2_case_w = tray_body_w_open() + 2 * v2_tray_xy_clearance + 2 * v2_wall;
v2_case_d = tray_d_open() + 2 * v2_tray_xy_clearance + 2 * v2_wall;
v2_case_h = 31.50;
v2_base_h = 16.25;
v2_lid_h = v2_case_h - v2_base_h;
v2_corner_r = 8.00;
v2_base_floor_t = 4.20;
v2_lid_roof_t = 3.40;

// One centered cartridge-registration well. Magnets retain the cartridge;
// the shallow well only locates it in X/Y and prevents lateral sliding.
v2_tray_recess_depth = 0.60;
v2_tray_recess_w = tray_body_w_open() + 2 * v2_tray_xy_clearance;
v2_tray_recess_d = tray_d_open() + 2 * v2_tray_xy_clearance;
v2_tray_recess_r = tray_body_corner_r_open() + v2_tray_xy_clearance;
v2_tray_x = 0;
// Keep the cartridge exactly centered in the enclosure. The compact front
// purchased roller catch now lives entirely in the symmetric front service margin.
v2_tray_y = 0;
v2_inner_w = v2_case_w - 2 * v2_wall;
v2_inner_d = v2_case_d - 2 * v2_wall;
v2_side_margin = (v2_inner_w - v2_tray_recess_w) / 2;
v2_front_margin = v2_inner_d / 2 -
                  (v2_tray_y + v2_tray_recess_d / 2);
v2_back_margin = v2_inner_d / 2 +
                 v2_tray_y - v2_tray_recess_d / 2;

// Four D4x2 magnets under the single cartridge. The base floor is deliberately
// thick enough to leave >1 mm of material below these pockets.
v2_floor_magnet_depth = tray_magnet_h + magnet_h_clearance;


// ---------------------------------------------------------------------------
// INTEGRATED HUMIDITY BAY + VENTED DROP-IN LID (2 x Boveda Size 8)
// ---------------------------------------------------------------------------
// Instead of a full removable cassette, the case now uses a shallow humidity
// bay built directly into the base floor. Two Size 8 packs sit in divided
// wells and a thin removable perforated lid simply rests on a surrounding
// ledge above them.
v2_humidity_bay_corner_r = 3.00;
v2_humidity_bay_pack_clearance = 0.80;
v2_humidity_bay_divider_t = 2.40;
v2_humidity_bay_pocket_w =
    boveda_w + 2 * v2_humidity_bay_pack_clearance;
v2_humidity_bay_pocket_d =
    boveda_d + 2 * v2_humidity_bay_pack_clearance;
v2_humidity_bay_inner_w =
    2 * v2_humidity_bay_pocket_w + v2_humidity_bay_divider_t;
v2_humidity_bay_inner_d = v2_humidity_bay_pocket_d;
v2_humidity_bay_opening_w = v2_humidity_bay_inner_w + 5.10;
v2_humidity_bay_opening_d = v2_humidity_bay_inner_d + 5.10;
v2_humidity_bay_x = 0;
v2_humidity_bay_y = 0;
v2_humidity_bay_floor_z = v2_base_floor_t;
v2_humidity_bay_depth = 6.60;
v2_humidity_bay_top_z = v2_humidity_bay_floor_z + v2_humidity_bay_depth;

// Tray-support frame around the bay. The reed cartridge lands on this frame,
// leaving the center open for the humidity bay cover.
v2_tray_bottom_z = v2_humidity_bay_top_z + 0.20;
v2_tray_support_h = v2_tray_bottom_z - v2_base_floor_t;
v2_tray_support_outer_w = v2_tray_recess_w;
v2_tray_support_outer_d = v2_tray_recess_d;
v2_tray_support_outer_r = v2_tray_recess_r;
v2_tray_support_inner_w = v2_humidity_bay_opening_w;
v2_tray_support_inner_d = v2_humidity_bay_opening_d;
v2_tray_support_inner_r = v2_humidity_bay_corner_r;
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

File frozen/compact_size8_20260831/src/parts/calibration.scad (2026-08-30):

/* Small hardware-fit coupon. Print this before a long enclosure print if the
   printer/material is unfamiliar. */

include <../lib/geometry.scad>
include <../lib/hardware.scad>

module fit_coupon() {
    plate_w = 72;
    plate_d = 24;
    plate_h = 4;
    bore_clearances = [0.15, 0.25, 0.35];

    difference() {
        rounded_prism([plate_w, plate_d, plate_h], 2.0);

        // Three vertical 2 mm pin gauges.
        for (i = [0 : len(bore_clearances) - 1])
            translate([-22 + i * 14, 0, -epsilon])
                cylinder(d = v2_hinge_pin_d + bore_clearances[i],
                         h = plate_h + 2 * epsilon,
                         $fn = is_fast_mesh ? 24 : 48);

        // One production-size D4x2 magnet pocket.
        translate([23, 0, plate_h - tray_magnet_h - magnet_h_clearance])
            magnet_pocket();
    }
}

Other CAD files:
.]/src/assembly.scad
.]/src/export_sheet.scad
.]/src/main.scad
.]/src/parts/case.scad
.]/src/parts/latch.scad
.]/src/parts/spring_mounts.scad
frozen/compact_size8_20260831/src/assembly.scad
frozen/compact_size8_20260831/src/export.scad
frozen/compact_size8_20260831/src/export_sheet.scad
frozen/compact_size8_20260831/src/main.scad
frozen/compact_size8_20260831/src/parts/case.scad
frozen/compact_size8_20260831/src/parts/latch.scad
frozen/compact_size8_20260831/src/parts/roller_catch.scad
frozen/compact_size8_20260831/src/parts/spring_mounts.scad
frozen/compact_size8_20260831/src/parts/tray.scad
src/parts/reed_plate.scad

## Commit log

2026-08-28 preliminary version
    [assembly.scad, calibration.scad, config.scad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]
2026-08-29 reed tray
    [assembly.scad, config.scad, main.scad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]
2026-08-29 nearly finished tray
    [config.scad, export.scad, main.scad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]
2026-08-29 prepare for prototype export
    [assembly.scad, config.scad, export.scad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]
2026-08-30 pre-latch code
    [assembly.scad, calibration.scad, case.scad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]
2026-08-30 better latch
    [assembly.scad, case.scad, config.scad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]
2026-08-30 fix latch design
    [assembly.scad, case.scad, config.scad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]
2026-08-30 boveda visualizations
    [assembly.scad, case.scad, main.scad]
2026-08-31 before latch removal
    [assembly.scad, case.scad, config.scad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]
2026-08-31 fix bottom bay
    [assembly.scad, case.scad, config.scad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]
2026-08-31 better honeycomb humidity bay lid
    [case.scad, config.scad, main.scad]
